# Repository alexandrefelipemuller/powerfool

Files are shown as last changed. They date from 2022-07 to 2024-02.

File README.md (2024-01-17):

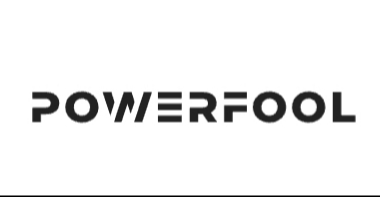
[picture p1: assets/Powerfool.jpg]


An Arduino Automobile Programmable Module

What is
---------------
It is a low cost automotive module used for many feature you want. The main idea is using Arduino Nano. It's not, at least not at first objective, a fuel injection and  spark management system. But, as it is opensource, the main idea is allow you to do anything.

Features
---------------
* Speedometer fix, by changing wheel size or other difference it can drift the signal
* Oil and fuel pressure sensor and warnings
* old Renault/General Motors Computer Board with distance per consume and autonomy (may work on other manufacturers)
* Shift light, shift stage, low battery warning, etc...
* Air temperature and oxygen sensor adjustment for tuning
* Emergency stop signal

Where to buy
---------------
You can make your own hardware using diagrams and source code on this site.

Support
---------------
Please contact autor and use Wiki here no Github

Diagram
---------------
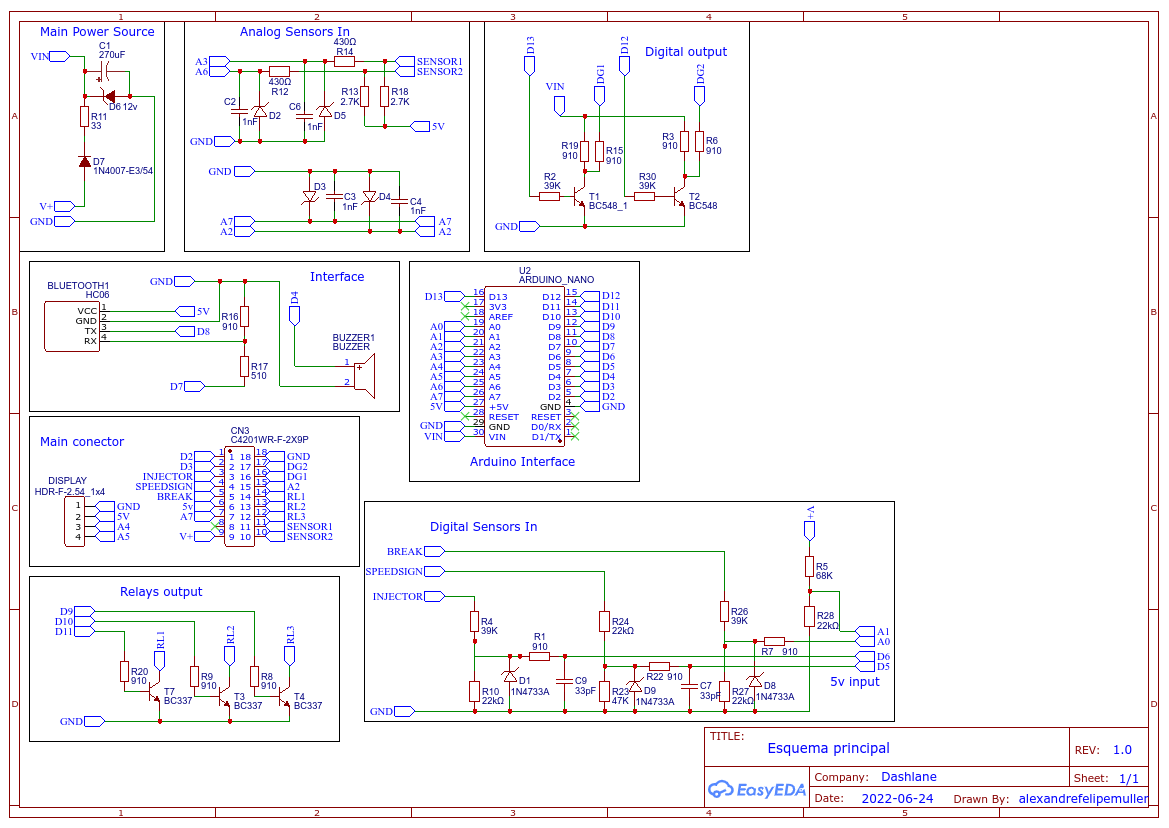
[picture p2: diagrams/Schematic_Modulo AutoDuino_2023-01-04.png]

A better explanation here: [Schematic Overview](Schematic.md)

# Understanding the Arduino Code for Vehicle Monitoring

This Arduino sketch (a term for an Arduino program) is designed for a vehicle or engine management system. It uses various sensors to monitor and control the engine's performance. Let's break down what each part does:

## 1. Sensor Inputs and Actuator Outputs:
   - The code sets up digital and analog inputs and outputs (I/O). Inputs read data from the environment (like a button press or a sensor reading), while outputs allow the Arduino to interact with other devices (like turning on a light or activating a motor).

## 2. Display and Bluetooth Communication:
   - The system is capable of displaying information on an LCD screen and communicating via Bluetooth. This might be used to show real-time data or for remote diagnostics.

## 3. Reading Sensor Values:
   - Sensors for pressure (`sensorPressure`), intake air temperature (`intakeAirTemp`), and another pressure sensor (`sensorPressure2`) are read by the Arduino. These measurements are crucial for understanding how well the engine is running.

## 4. Fuel Consumption Calculation:
   - The code computes fuel consumption based on the injector's pulsing frequency and their flow rate, which is defined as 20 lbs/h at 12V.

## 5. Speed Management and Alerts:
   - There are functions to handle speed limits, automatic door locking at certain speeds, and emergency braking indicators.

## 6. Odometer and Mileage Tracking:
   - The system keeps track of distance traveled and fuel used, functioning as an odometer and trip meter, which are saved in non-volatile memory (EEPROM) to be retained even after the power is turned off.

## 7. RPM and Pressure Management:
   - Alerts are generated if the engine's RPM exceeds a set limit or if sensor pressure drops below a certain threshold while at high RPMs.

## 8. Diagnostic Mode:
   - A diagnostic mode can display detailed reports on the LCD, which could be helpful for troubleshooting.

## 9. Timers and Pulse Outputs:
   - Timers are used to precisely manage pulse outputs for controlling various timed functions, possibly related to the engine control.

### Code Components:

- `#define`: These lines define constants or settings that can be easily changed at the top of the code.
- `#include`: This includes libraries that add functionality, like controlling an LCD screen or handling Bluetooth communication.
- Variables: Variables like `sensorPressure` are named locations in memory where sensor data is stored.
- `setup()`: A function that runs once when the Arduino is powered on. It's used to initialize I/O pins and set up communication.
- `loop()`: This function runs repeatedly, forming the main part of the program. It reads sensors, calculates values, and responds to changes.
- Functions: These are blocks of code that perform specific tasks, like `calculateDistance()` or `alertsManager()`, and can be called whenever those particular tasks need to be performed.
  
### Powerfool Project Architecture

This document outlines the proposed software architecture for the Powerfool project. The architecture is designed to enhance modularity, clarity, and ease of maintenance.

#### 1. Core Application
- **File**: `powerfool.ino`
- **Description**: The main entry point of the application. It initializes the system, manages the main loop, and coordinates high-level application flow.
- **Responsibilities**:
  - System Initialization
  - Main Loop Control
  - High-Level State Management

#### 2. Communication Module
- **Files**: `bluetooth.ino`, `bluetooth.h`
- **Description**: Handles all Bluetooth-related functionalities.
- **Responsibilities**:
  - Bluetooth Connection Management
  - Data Transmission and Reception
  - Error Handling in Communication

#### 3. Display Module
- **Files**: `display.ino`, `display.h`
- **Description**: Manages the user interface on the display.
- **Responsibilities**:
  - Rendering UI Elements
  - Displaying Status and Notifications
  - Handling Screen Refresh and Updates

#### 4. Input/Output Tools
- **Files**: `iotools.ino`, `iotools.h`
- **Description**: Manages input/output operations, including reading sensors or interfacing with other hardware components.
- **Responsibilities**:
  - Sensor Data Acquisition
  - Actuator Control
  - Input Processing

#### 5. Menu System
- **Files**: `menu.ino`, `menu.h`
- **Description**: Handles the menu interface for user interactions.
- **Responsibilities**:
  - Menu Navigation
  - User Input Handling
  - Menu-related Display Updates

#### Additional Recommendations
- **Configuration File**: `config.h` file for all global settings and constants.

### EEPROM Memory:
- The EEPROM is a type of memory that retains its contents even when the power is turned off. It's used here to store important values like total mileage and settings.
- See in menu.ino the description of the main memory

### Arduino Pins:
- Pins are the points on the Arduino board where you connect sensors and actuators. In the code, `A0`, `A1`, etc., refer to analog input pins, and numbers like `10`, `11`, `12` refer to digital I/O pins.

## In Conclusion:
This sketch is a comprehensive program for a vehicle monitoring system. It's designed to interact with the physical world through sensors and actuators, perform calculations, and save important information for future use. For a beginner, understanding this code can be a fantastic introduction to the world of embedded systems and automotive electronics.

---

*Remember, the best way to learn is by doing. So, if you're a beginner, try uploading this code to an Arduino and see what each part does. Change values, see how the system responds, and get a feel for how software can control hardware.*

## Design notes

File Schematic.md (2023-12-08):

# Principal Schematic Overview

The schematic represents a simple electronic circuit, potentially for a vehicle's monitoring or control system. Here is a breakdown of its sections:

## Main Power Source
- The main power input is denoted by `V+` and `GND` symbols.
- There's a stabilizing circuit with a `C1` capacitor for smoothing voltage fluctuations in VIN (12v).

## Analog Sensors In
- Two sensors (`SENSOR1` and `SENSOR2`) are connected through resistors to the analog inputs `A3` and `A6`.
- Each sensor circuit includes a diode for protection and a filtering capacitor.

## Digital Output
- The digital output section features two transistors (`BC548`) that control digital signals, likely to power devices or for signal processing.

## Interface
- A Bluetooth module (`HC06`) is wired for serial communication, indicated by `RX` and `TX` lines.
- There's a buzzer (`BUZZER1`) connected through a resistor and a transistor, used for audible alerts.

## Main Connector
- A connector (`CN3`) is illustrated with multiple lines for `DISPLAY`, `INJECTOR`, `SPEEDSIGN`, `BREAK`, and `SENSORS`, suggesting multiple input and output connections for various subsystems.

## Arduino Interface
- An Arduino Nano (`U2`) is shown with connections to digital and analog pins, demonstrating the integration of a microcontroller for processing and control.

## Digital Sensors In
- There are additional inputs for digital sensors, with a resistor and capacitor network for signal conditioning.

## Relays Output
- Several relays (`D9`, `D10`, `D11`) are connected, which are controlled by transistors (`BC337`). These relays likely switch higher power loads.

## 5V Output
- A separate output for 5V is indicated, which might be used for sensors

---

This schematic is indicative of a multi-faceted electronic system with capabilities for sensor integration, actuator control, power management, and communication interfaces, which could be part of an automotive or robotic application.

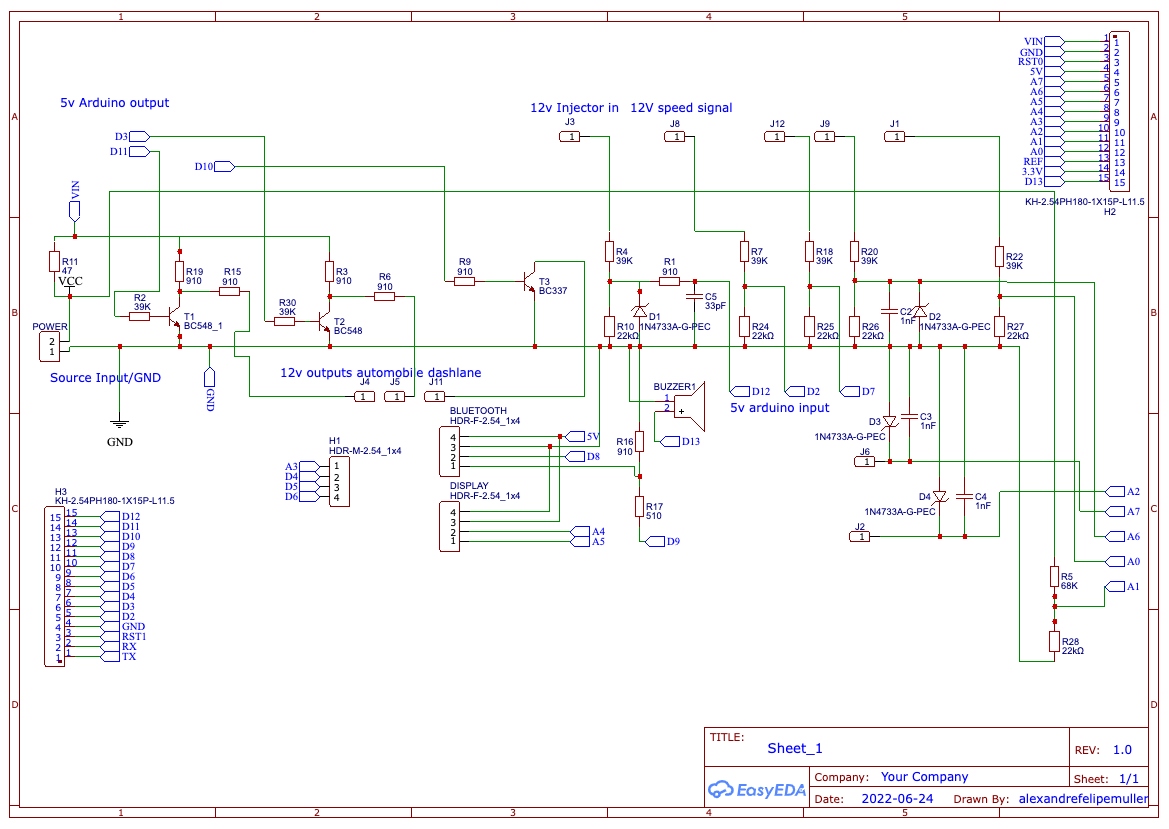
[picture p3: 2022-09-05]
diagrams/Schematic_Modulo AutoDuino_2022-09-05.png

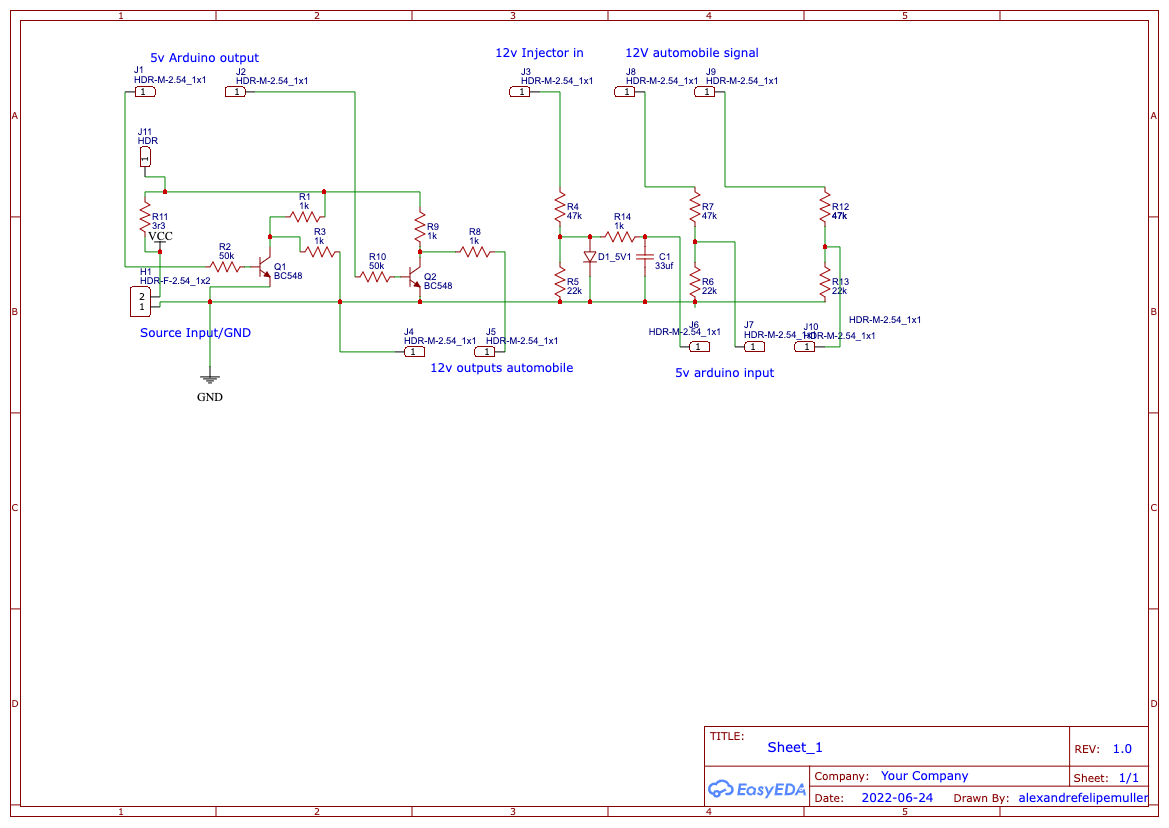
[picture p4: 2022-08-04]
diagrams/Schematic_Modulo AutoDuino_2022-07-21.png

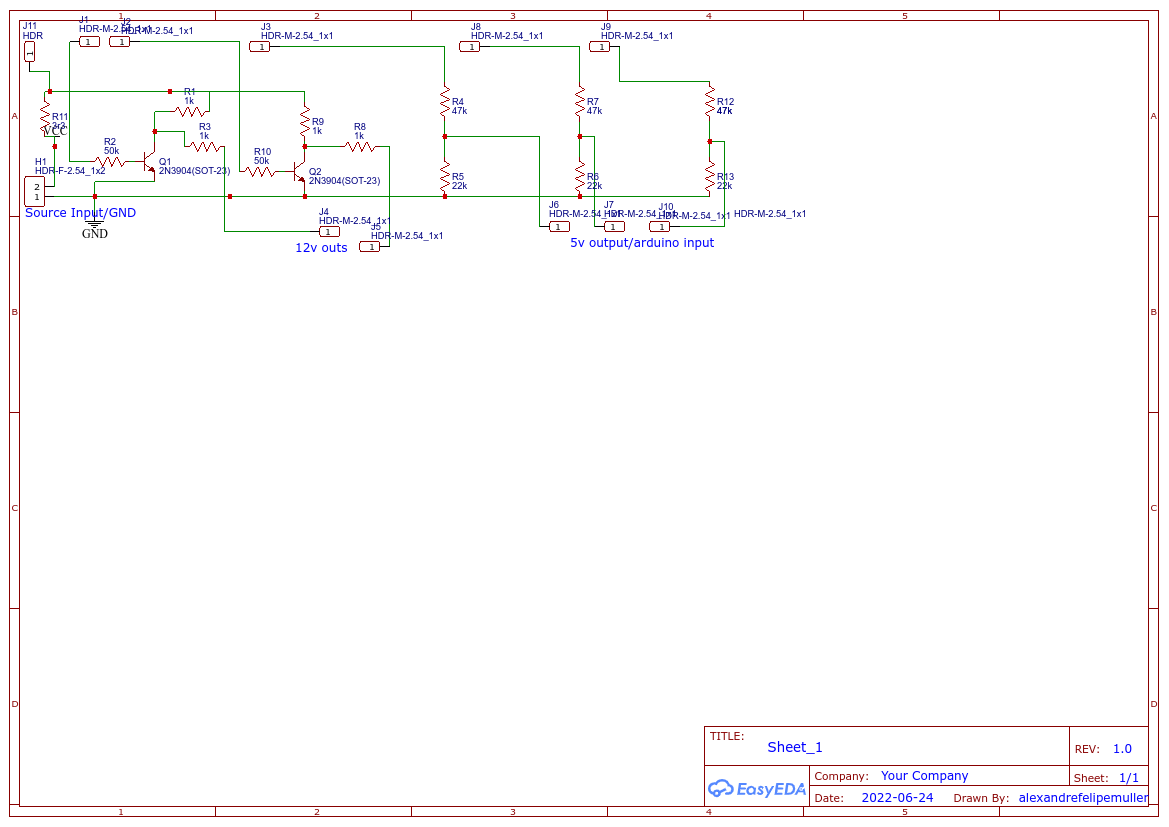
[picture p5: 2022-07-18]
diagrams/Schematic_Modulo AutoDuino_2022-07-18.png

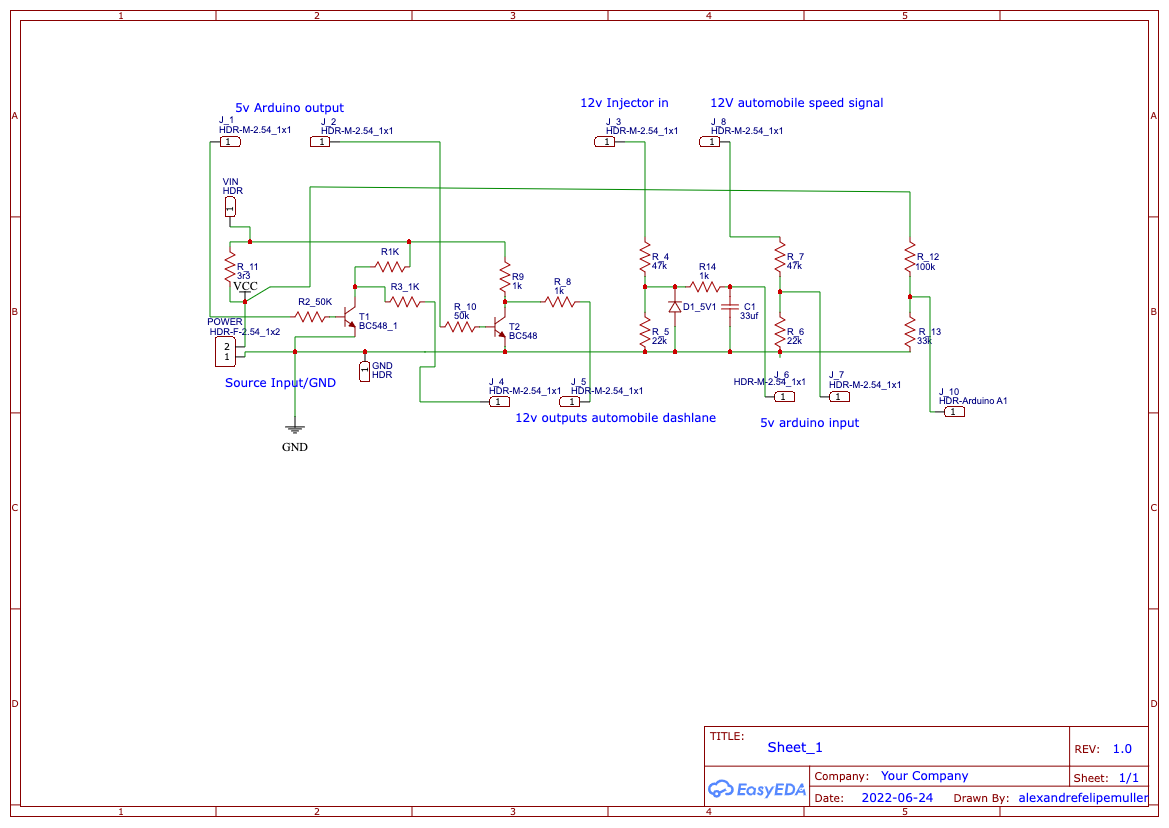
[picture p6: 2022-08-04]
diagrams/Schematic_Modulo AutoDuino_2022-08-04.png

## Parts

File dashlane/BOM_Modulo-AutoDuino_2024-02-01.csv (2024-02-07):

ID | Name | Designator | Footprint | Quantity | Manufacturer Part | Manufacturer | Supplier | Supplier Part | Price | Pins | Resistance
1 | BZT52C12_C727004 | D06 | SOD-123_L2.7-W1.7-LS3.8-RD | 1 | BZT52C12 | TWGMC(台湾迪嘉) | LCSC | C727004 | 0.013 | 2
2 | 220uF | C1 | CAP-TH_BD8.0-P3.50-D0.6-FD | 1 | KM227M035F12RR0VH2FP0 | CX(承兴) | LCSC | C2063 | 0.027 | 2
3 | Bluetooth | U1 | HDR-TH_4P-P2.54-H-F-W10.2 | 1 | KH-2.54FH90-1X4P-H8.5 | kinghelm(金航标) | LCSC | C2932680 | 0.076 | 4
4 | BC337 | T1 | BC548C | 1 | BC337 | Jiangsu Changjing Electronics | LCSC | C328602 | 0.016 | 3
5 | BC337 | T2 | BC548C | 1 | BC337 | Jiangsu Changjing Electronics Technology Co., Ltd. | LCSC | C328602 | 0.016 | 3
6 | 33pF | C7,C9 | C0603 | 2 | GRM1882C1H330JA01D | muRata(村田) | LCSC | C85970 | 0.006 | 2
7 | 430Ω | R12,R14 | RES-TH_BD1.8-L3.2-P7.20-D0.4 | 2 | MF1/8W-430Ω±1%T52 | Huaxing Mechanical-Elec. | LCSC | C713906 | 0.005 | 2 | 430Ω
8 | 2.7K | R13,R18 | RES-TH_BD2.4-L6.3-P10.30-D0.6 | 2 | MFR-25FTE52-2K7 | YAGEO | LCSC | C172999 | 0.011 | 2 | 2.7kΩ
9 | C4201WR-F-2X9P | CN3 | CONN-TH_C4201WR-F-2X9P | 1 | C4201WR-F-2x9P | CJT(Changjiang Connectors) | LCSC | C428857 | 0.552 | 18
10 | HDR-F-2.54_1x4 | DISPLAY | HDR-F-2.54_1X4 | 1 |  |  | LCSC | C225501 | 0.071 | 4
11 | 910 | R7,R22,R20,R8,R1,R3,R6,R9,R15,R16,R19 | RES-TH_BD1.8-L3.2-P7.20-D0.4 | 11 | MF1/8W ±1% 910Ω OTB5E | FlyWin | LCSC | C337120 | 0.006 | 2 | 910Ω
12 | 33 | R11 | RES-TH_BD3.3-L9.0-P13.00-D0.6 | 1 | MFR1WSJT-52-33R | YAGEO | LCSC | C176430 | 0.025 | 2 | 33Ω
13 | 1N4733A | D9,D8,D5,D1,D2 | DO-41G_BD2.4-L4.0-P8.00-D0.7-RD | 5 | 1N4733A-G-PEC | PANJIT International | LCSC | C112411 | 0.06 | 2
14 | 47K | R23 | RES-TH_BD1.7-L3.5-P7.50-D0.5 | 1 | RN 1/8W 47K F T/B A1 | TyoHM | LCSC | C433476 | 0.008 | 2 | 47kΩ
15 | ARDUINO_NANO | U2 | COMM-TH_ARDUINO_NANO | 1 | ARDUINO_NANO | null | LCSC | C9900017879 |  | 30
16 | 39K | R26,R2,R4,R30 | RES-TH_BD2.3-L3.7-P7.70-D0.9 | 4 | - | FlyWin | LCSC | C337041 | 0.003 | 2 | 39kΩ
17 | 22kΩ | R27,R10,R24,R28 | RES-TH_BD1.8-L3.2-P7.20-D0.4 | 4 | MF1/8W-22KΩ±1%T52 | Huaxing Mechanical-Elec. | LCSC | C713923 | 0.006 | 2 | 22kΩ
18 | BC337 | T7,T4,T3 | BC548C | 3 | BC337 | Foshan Blue Rocket Elec | LCSC | C328602 | 0.016 | 3
19 | 1nF | C6,C4,C3,C2 | C0603 | 4 | CL10B102KB8NNNC | SAMSUNG | LCSC | C1588 | 0.003 | 2
20 | 1N4007-E3/54 | D7 | DO-41_BD2.4-L4.7-P8.70-D0.9-FD | 1 | 1N4007-E3/54 | VISHAY | LCSC | C3011149 | 0.011 | 2
21 | BUZZER | BUZZER1 | BUZ-TH_BD12.0-P7.60-D0.6-FD | 1 | TMB12A05 | YUEXIN | LCSC | C781860 | 0.214 | 2
22 | 1N4733A-G-PEC | D3,D4 | DO-41G_BD2.4-L4.0-P8.00-D0.7-RD | 2 | 1N4733A-G-PEC | PANJIT International | LCSC | C112411 | 0.06 | 2
23 | 68K | R5 | RES-TH_BD1.8-L3.2-P7.20-D0.4 | 1 | - | Chian Chia Elec | LCSC | C119221 | 0.008 | 2 | 68kΩ
24 | 510 | R17 | RES-TH_BD1.9-L3.4-P7.40-D0.5 | 1 | MFR-12JT-52-510R | YAGEO | LCSC | C176393 | 0.015 | 2 | 510Ω

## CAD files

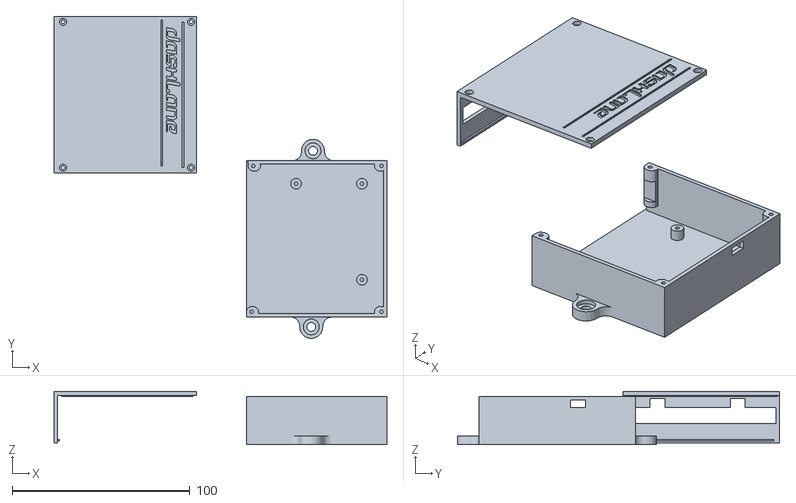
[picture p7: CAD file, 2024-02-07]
dashlane/Dashlane case.stl
187.0 x 181.0 x 30.0

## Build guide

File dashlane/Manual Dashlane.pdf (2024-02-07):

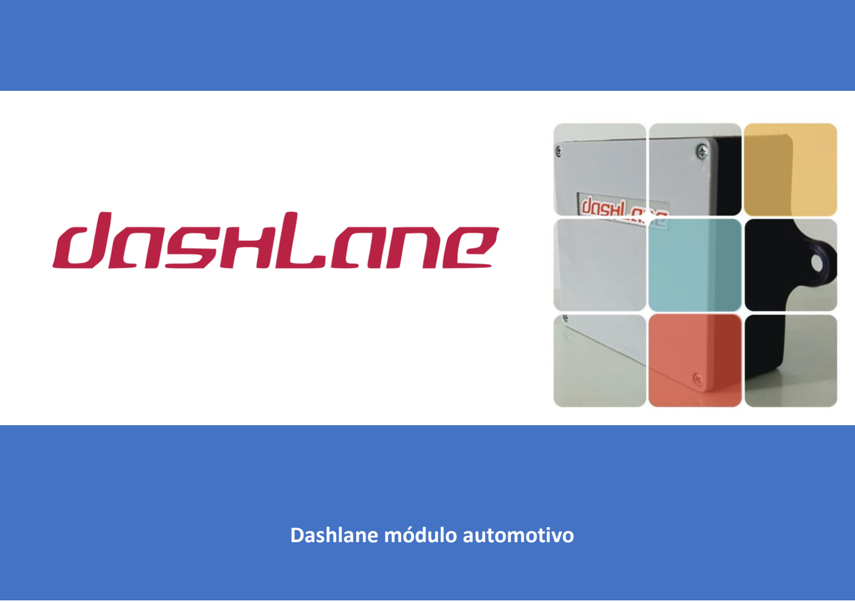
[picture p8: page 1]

0

## Dashlane módulo automotivo

## Introdução

1

1

## Introdução

2

2

## Índice

Seção 2) | Computador de bordo original ........4
Seção 3) | Aviso de frenagem de emergência...4
Seção 4) | Abertura e fechamento de portas....4
Seção 1) | Diagrama do conector principal.......6

Menu 3 – Velocidade média, consumo médio .........11

## Introdução

3

3

Capítulo 5 Firmware e informações gerais.......18

Seção 1) | CopyLeft e ausência de garantia ....18
Seção 1) | Vista interna e descrição

## Introdução

4

4

## Capítulo 1 Introdução

Parabéns! Ao adquirir esse produto você agora faz parte de uma comunidade. O módulo Dashlane é um microcontrolador programável que pode ser usado e modificado.

### Seção 1) Apresentação

Ver anexo, o Módulo possui duas portas de comunicação:
- Chicote principal, conector minifit 18 vias
- Porta USB

## Capítulo 2 Funções

### Seção 1) Divimult

Permite ajustes sinal de velocidade para mais ou para menos, para ajustes de diferença de sensor, roda ou painel. Correção do hodômetro.

### Seção 2) Computador de bordo original

Cálculo do combustível consumido através de leitura de um injetor, e saída de consumo para painéis que utilizam esse sinal.

### Seção 3) Aviso de frenagem de emergência

Sinalização de frenagem de emergência: automaticamente o pisca-alerta entra em funcionamento quando o carro é freado bruscamente, servindo de alerta aos outros motoristas. Padrão acima de 80 km/h desaceleração superior a 7 m/s²

### Seção 4) Abertura e fechamento de portas

Travamento das portas quanto atinge determinada velocidade.

## Funções

5

5

### Seção 5) Avisos sonoros

Aviso sonoro de limitador de velocidade e rotação excessiva do motor.

### Seção 6) Proteções do motor

Leitura de sinal de pressão (seja óleo ou combustível), ou temperatura para proteção do motor.

### Seção 7) Display LCD

Ver as principais informações através de um display LCD avulso.

### Seção 8) Bluetooth

Ver as principais informações através do aplicativo RealDash para Android.

### Seção 9) Cronômetro de volta

Marcar tempo de volta através de um botão instalado a parte.

## Instalação

6

6

## Capítulo 3 Instalação

### Seção 1) Diagrama do conector principal

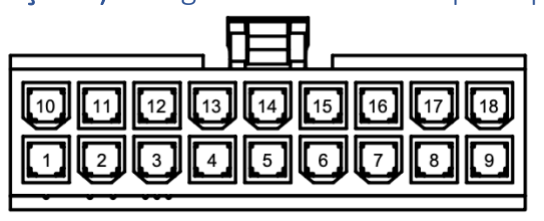
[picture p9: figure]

Atenção: Vista de frente do módulo

PINO | FUNÇÃO
1 | + Pós Chave 12v
2 | Sem uso
3 | Entrada 1 Analógica 5v (sensor 3 fios)
4 | + Saída 5v para Sensores
5 | Entrada Digital 3, Sensor 12v
6 | Entrada Digital 2, Sensor 12v
7 | Entrada Digital 1, Sensor 12v
8 | - Botão 1
9 | - Botão 2
10 | - Negativo
11 | Saída 1 digital 12v (painel)
12 | Saída 2 digital 12v (painel)
13 | Entrada 2 Analógica 5v (sensor 3 fios)
14 | Saída Relé 1
15 | Saída Relé 2
16 | Saída Relé 3
17 | Sensor 1 (resistivo)
18 | Sensor 2 (resistivo)
Atenção: As cores dos fios não possuem padrão, podem variar de um chicote a outro e portanto devem ser desconsideradas.

### Seção 2) Informações importantes

Antes de começar qualquer instalação elétrica desconecte os polos da bateria. É aconselhável ligar negativo do módulo diretamente ao negativo da bateria. É indispensável uso de ferramentas como multímetro ou caneta testadora.

## Instalação

7

7

A ligação inadequada apresentará possível dano irreversível. Por tanto certifique-se que está ligando corretamente o sinal.
Planeja-se e determine onde a central será instalada e quais dispositivos serão conectados (sensores, painéis de controle, etc.). Também que o componente de campainha interno será audível.

Fios não utilizados devem obrigatoriamente ser isolados.

### Seção 3) Sugestão de ligação básica

- Negativo – Direto da bateria
- Positivo – Pós chave
- Entrada Digital 1 – Negativo do Bico injetor (veja detalhes a seguir)
- Entrada Digital 2 – Sensor de velocidade, roda ou caixa de marcha. Entrada de velocidade (necessário para Computador de Bordo)
- Entrada Digital 3 – Luzes de freio (somente se for usar ESS)
- Saída Digital 1 - Saída de
consumo (ver a seguir)
- Saída Digital 2 - velocidade (painel), Somente se for utilizar divimulti

Como encontrar sinal do negativo do bico injetor: De um injetor qualquer, testar com injetor desconectado entre os dois fios, qual fio possui 12v no pós chave e ligar no outro fio.

Sinal de consumo no painel (somente para computador de bordo original):
Renault Sandero/Logan painel digital - pino 19 tomada cinza
Renault Clio/Scenic mostrador do tanque com ponteiro - pino 7 tomada vermelha
Uno mile fire - MR/ AM pino B08 Corsa/Classic/Vectra B- pino 27 MID (painel central)

Se o pino estiver faltando no plug usar um conector femea kk tipo molex.

## Instalação

8

8

Sinal de velocidade (para ser usado sinal para entrada ou saída):
Renault Sandero/Logan painel digital - pino 22 tomada preta do painel
Renault Clio/Scenic mostrador do tanque com ponteiro - pino 23 tomada cinza do painel
Ou sensor da caixa.
Saída do módulo para o painel
Tipicamente 27 Hz = 20km/h, 135Hz = 100 km/h

Botão troca de menu do computador de bordo original.
Caso queira utilizar computador de bordo original do painel é necessário instalar botão com sinal negativo (que vai pro painel diretamente):
Renault Sandero/Logan painel digital - pino 23 tomada preta do painel
Renault Clio/Scenic mostrador do tanque com ponteiro - pino 6 tomada vermelha do painel Corsa/Classic - pino 24 MID

### Seção 4) Fechamento de portas

Ao atingir determinada velocidade configurada pelo terminal USB a saída “Rele 2” é acionada por 400 milissegundos. Nessa saída deve ser ligado o botão de travamento de portas onde será acionado o travamento.
No fio correspondente a essa porta haverá um sinal negativo como na figura 1 na seção seguinte. Não ultrapassar corrente de 1A nessa porta.

### Seção 5) Frenagem de emergência ESS

Ao atingir desaceleração superior a 7m/s²

a saída
“Rele 3” é acionada por 500 milissegundos. Nessa saída deve ser ligado o botão alerta onde será acionado o alerta. Esse recurso só funciona com sinal de freio na porta entrada digital 3.
No fio correspondente a essa porta haverá um sinal negativo como na figura 1 na seção

## Instalação

9

9

seguinte. Não ultrapassar corrente de 1A nessa porta.

Seção 6) Divimult
Caso vá utilizar a função Divimult será necessário ligar Entrada Digital 2 e Saída Digital 2 do Dashlane. Podendo ser sensores indutivos ou hall. A saída do dashlane necessariamente é uma onda quadrada.

### Seção 7) Proteções do motor

É possível implementar até 2 sensores de pressão do tipo PS10 que monitoram condições de baixa pressão de óleo ou combustível.

Para esta função a instalação precisa ter:
- Rele 1 – Por exemplo rele normalmente fechado ligado em série na bobina
- Entrada Digital 1 sinal do RPM ( por ex. bico injetor)
- Saída 5v estabilizada
- Entrada sinal analógico (pino 3 ou 13)

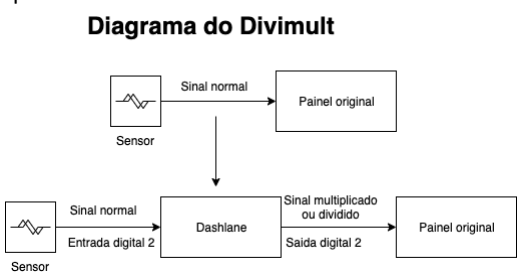
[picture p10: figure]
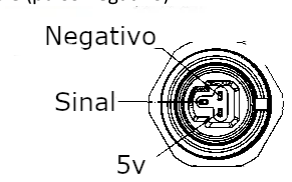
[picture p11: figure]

Saída relé (pulso negativo)

## Instalação

10

10

Relé de saída
Acionado no momento do alerta
Recomendado relé de no máximo 18 ohms, corrente máxima da saída de 1 ampere.

Devido a construção do relé com bobina interna o desligamento do relé pode gerar picos de alta tensão reversa particularmente danosa a circuitos eletrônicos. É fortemente recomendado a instalação de um diodo 1N4001 em paralelo com relé.

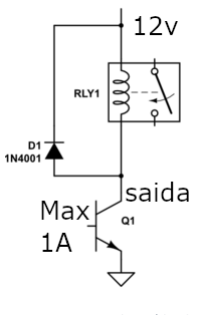
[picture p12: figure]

Figura 1 Exemplo saída de relé

Sugestões extras de ligação
- Sensor 1 – Temperatura da água radiador
- Sensor 2 – Temperatura do ar da admissão
- Rele 2 – Botão travamento das portas
- Rele 3 – Acionamento do pisca alerta

## Instalação

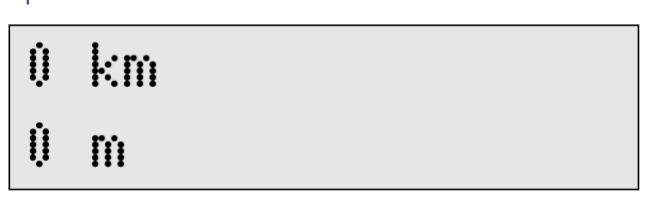
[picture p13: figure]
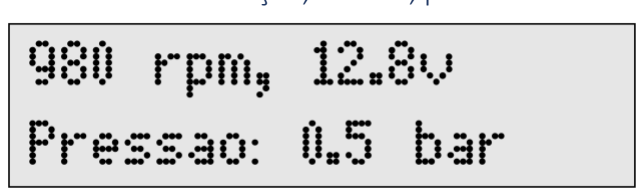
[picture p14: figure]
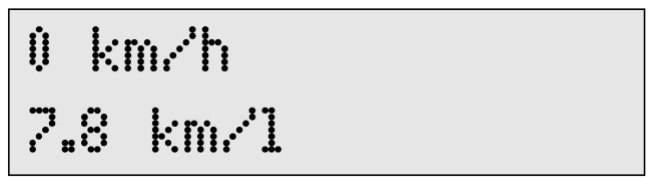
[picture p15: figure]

11

11

### Seção 8) Display

É possível instalar um display LCD 16x2 (de todas as cores) vendido separadamente.
A instalação usa 4 fios separados da tomada principal. São eles:
- Negativo
- Positivo 5v
- Sinal de Clock (SCL)
- Sinal de dados (SDA)

Se o seu módulo não possui 4 fios disponível basta conectar 4 jumpers dentro da placa principal. Mais informações veja o capítulo: Informações Técnicas

Através do Botão 1 (Menu) é possível alternar o menu do display.
Através do Botão 2 (Set) é possível configurar o menu selecionado.

Menu 1 - Hodômetro total e parcial

Menu 2 - Rotação, bateria, pressão sensor

Menu 3 – Velocidade média, consumo médio

## Instalação

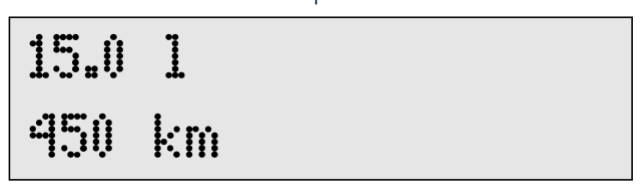
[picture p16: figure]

12

12

Menu 4 – Temperatura Sensor 1 e 2

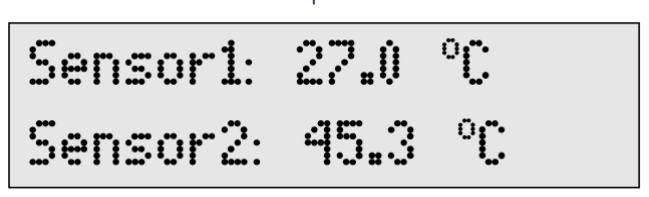
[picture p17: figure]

Menu 5 – Lap Timer

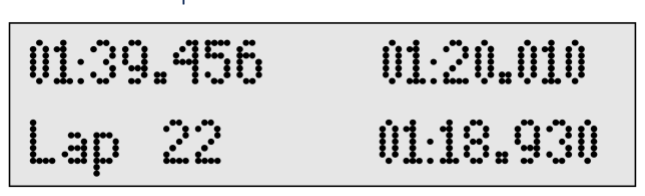
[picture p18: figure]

Tempo da volta atual e tempo da última volta. Número da volta atual e tempo de melhor volta

Menu 6 – Litros no tanque e autonomia

Litros no tanque desde que zerado hodômetro e autonomia esperada. Para atualizar a quantidade do tanque o usuário deve utilizar o botão set que soma + 5 litros.

### Seção 9) Bluetooth

É possível visualizar os dados do módulo através do aplicativo RealDash para Android

## Ajustes

## Capítulo 4 Ajustes

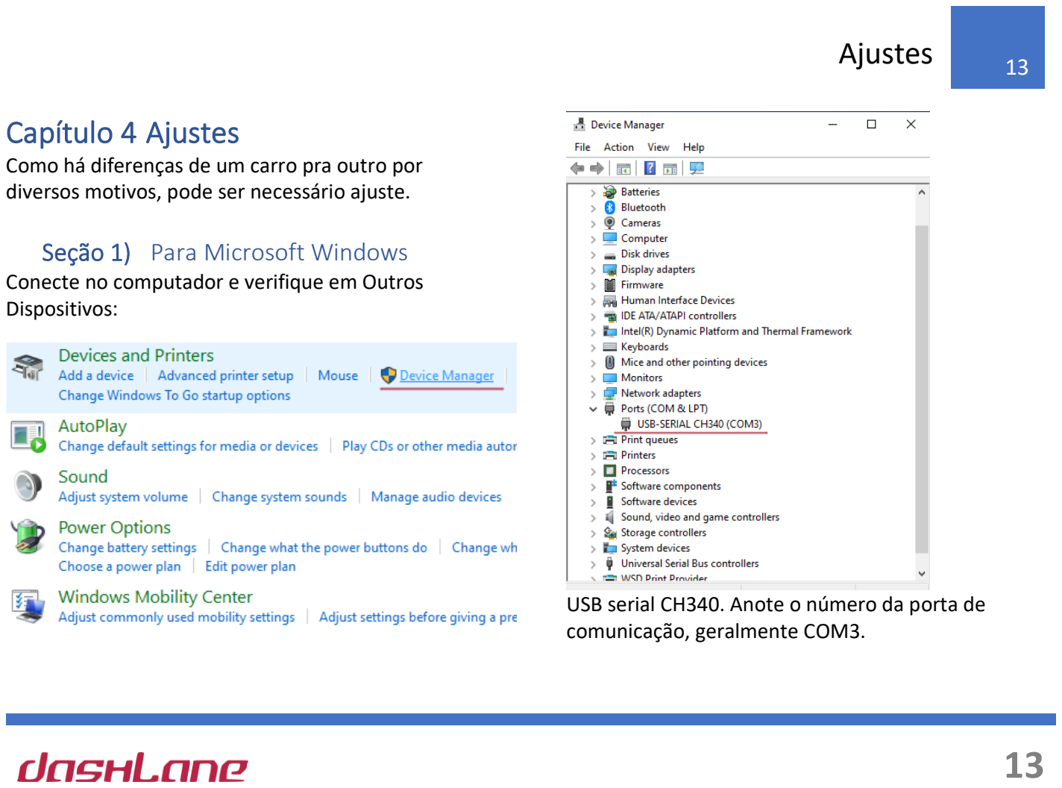
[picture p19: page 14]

13

13

Como há diferenças de um carro pra outro por diversos motivos, pode ser necessário ajuste.

### Seção 1) Para Microsoft Windows

Conecte no computador e verifique em Outros Dispositivos:

USB serial CH340. Anote o número da porta de comunicação, geralmente COM3.

## Ajustes

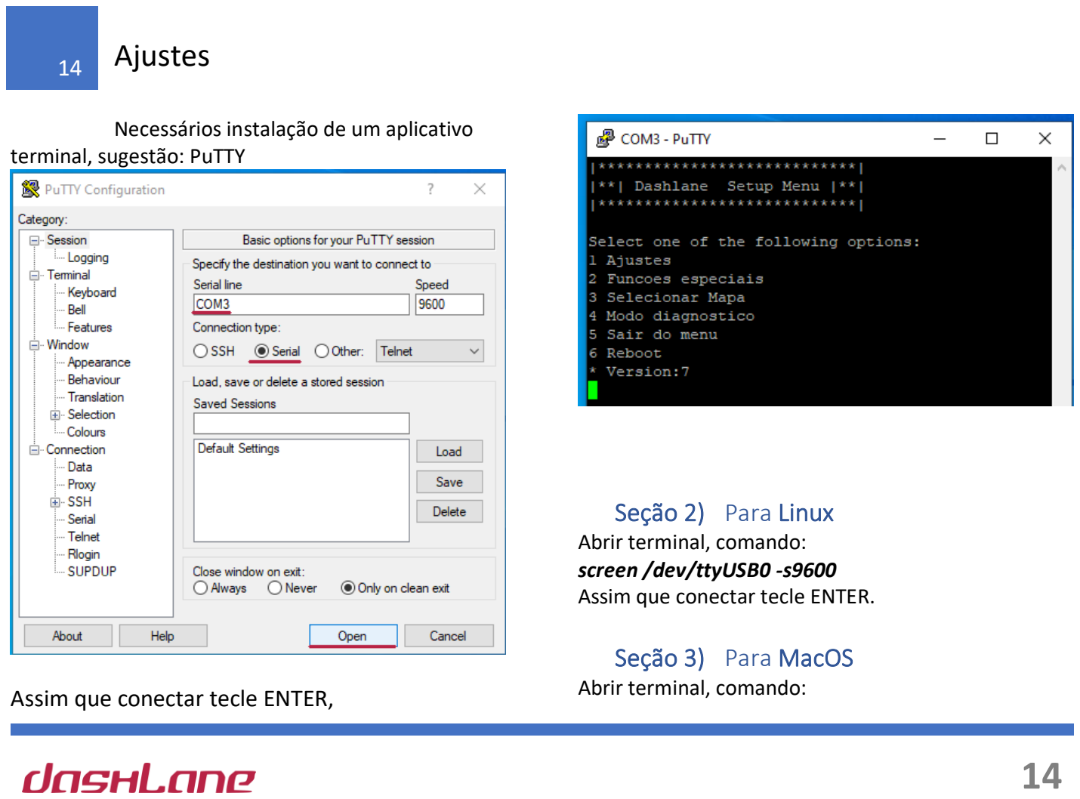
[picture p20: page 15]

14

14

Necessários instalação de um aplicativo terminal, sugestão: PuTTY

Assim que conectar tecle ENTER,

### Seção 2) Para Linux

Abrir terminal, comando:
screen /dev/ttyUSB0 -s9600 Assim que conectar tecle ENTER.

### Seção 3) Para MacOS

Abrir terminal, comando:

## Ajustes

15

15

screen /dev/*usbserial*
Assim que conectar tecle ENTER.

### Seção 4) Informações gerais

Após conectado, ligue modo diagnóstico (4) com motor funcionando para ver os valores lidos.

Todos os sinais podem ser ajustados pela porta USB em até +400% e -99%

Entrada do sensor de velocidade Aqui é possível ajustar o que é chamado de “constante K” vulgarmente falando quantos pulsos por km rodado. Esse valor usado pelo hodômetro e computador de bordo interno. Alguns valores de referencia:
- VW antigo 1800
- Renault 4860
- VW Fox 5000
- Chevrolet 15200

Ajuste do velocímetro
Permite ajustar sinal de velocidade e hodômetro em caso de troca de diâmetro das rodas, troca de sensor, troca de painel e etc...

Melhor forma de ajustar é pela distância percorrida do hodômetro, se for ajustado pela velocidade do GPS o hodômetro marcará a menos.

Tipo de injeção
Usado na referencia de rotação
Sequencial: um pulso por rotação do motor Semi-Sequencial: dois pulsos por rotação do motor

Primeiro ajuste do computador de bordo
Sinal de consumo instantâneo – Permite funcionamento de computador de bordo em painéis compatíveis com sinal de consumo instantâneo.

## Ajustes

16

16

Valor normal de consumo na marcha lenta mais ou menos 0.5ml/s
- Encha tanque, zere hodômetro. Depois de consumido, divida valor do hodômetro pelo valor consumido na bomba.

Por exemplo 500 km / 46 litros = 10,8 km/l Se medido no painel foi por exemplo 4 km/l, faça conta:
Medido no painel / Medido na bomba, por exemplo 4 / 10.8 = 0.37
- Subtraia 1 desse valor 0,37 -1 = -0,63
- O ajuste é -63% (mesmo procedimento pra valores acima do medido)
- Por exemplo se painel tivesse dado 15km/l, então 15/10.8 = 1,38. Portando 1,38 -1 = 0,38. Ajuste de +38%.

O ajuste pode ser feito por outro parâmetro: combustível consumido. Apenas medindo na bomba. Esse procedimento igualmente certo.

Ajustes Funções especiais

- Shift Beep (rpm do beep para troca de marcha, 0 desabilitado)
- RPM mínimo de acionamento do alerta (0 desabilitado)
- Pressão mínima de acionamento do alerta sensor 1 (1.000 = 1 bar de pressão)
- Pressão mínima de acionamento do alerta sensor 2 (1.000 = 1 bar de pressão)
- Aviso velocidade excedida em km/h: Velocidade em km/h que alerta com beep
- Tipo do beep de velocidade: continuo (fica alertado até velocidade baixar) ou curto (apenas dois beep curtos)

## Ajustes

17

17

- Travamento automático das portas: quantos km/h deve travar as portas na saída RL2 (0 é desabilitado).

## Firmware e informações gerais

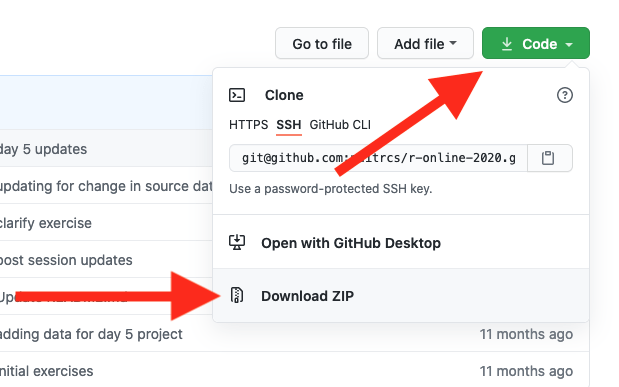
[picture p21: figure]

18

18

## Capítulo 5 Firmware e informações gerais

### Seção 1) CopyLeft e ausência de garantia

É dada liberdade de modificar, distribuir suas modificações, o código do programa que roda no módulo está disponível para estudo e modificação. Você pode alterá-lo e estuda-lo, porém suas modificações podem trazer efeitos adversos, por esse motivo somente pode ser exigido garantia com programa que esteve gravado originalmente no módulo.

### Seção 2) Baixando código fonte

Caso você deseja modificar o seu módulo para programa-lo a fazer qualquer coisa, gravar um novo firmware é o primeiro passo.

Abra o link do projetoi e clique em Clone e Download as Zip

### Seção 3) Gravando firmware novo

Faça download do Arduino IDE ii, e clique em Abrir, depois de descompactado o zip abra “powerfool.ino”.
Conecte o módulo a porta USB, feche todo e qualquer terminal que eventualmente esteja aberto.

## Firmware e informações gerais

19

19

Selecione Tools -> Selecione dispositivo Arduino Nano, no menu logo abaixo selecione tipo de processador ATmega328p (old bootloader).
Clique na seta pra direita da barra de ferramentas e espere até que apareça: “Carregado.” (deve-se ouvir o bip confirmando que o dispositivo foi reiniciado)
Esse código é feito de forma coletiva, a sua participação pode ajudar futuros usuários a terem uma melhor experiência.

## Suporte

20

20

## Capítulo 6 Suporte

Pelas redes sociais @dashlanemodulos no Instagram ou no Facebook

## Informações Técnicas

21

21

## Capítulo 7 Informações Técnicas

### Seção 1) Vista interna e descrição componentes:

BLUETOOTH | Modulo HC06
C1 | Capacitor 270uF
C2,3,4,6 Capacitor 1nF
C7,9 Capacitor 33pF
D1-5,7-9 Diodo Zener 5v.1 1N4733A
D6 | Diodo Zener 12v
R2,4,30,26 | Resistor 39K
R5 | Resistor 68K
R1,3,5,6,7,8,9,15,16,19,20,22Resistor 910R R11 Resistor 33R
R12,14 Resistor 430R
R17 Resistor 510R
R13,18 Resistor 2.7K
R23 | Resistor 47K
R10,24,27,28 | Resistor 22kΩ
T1,T2 | Transistor BC548
T3,T4,T7 Transistor BC337
U2 Arduino Nano

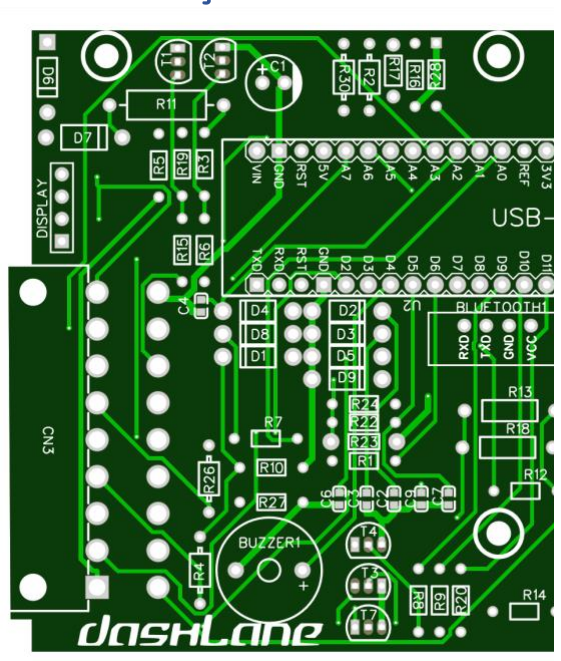
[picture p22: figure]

## Informações Técnicas

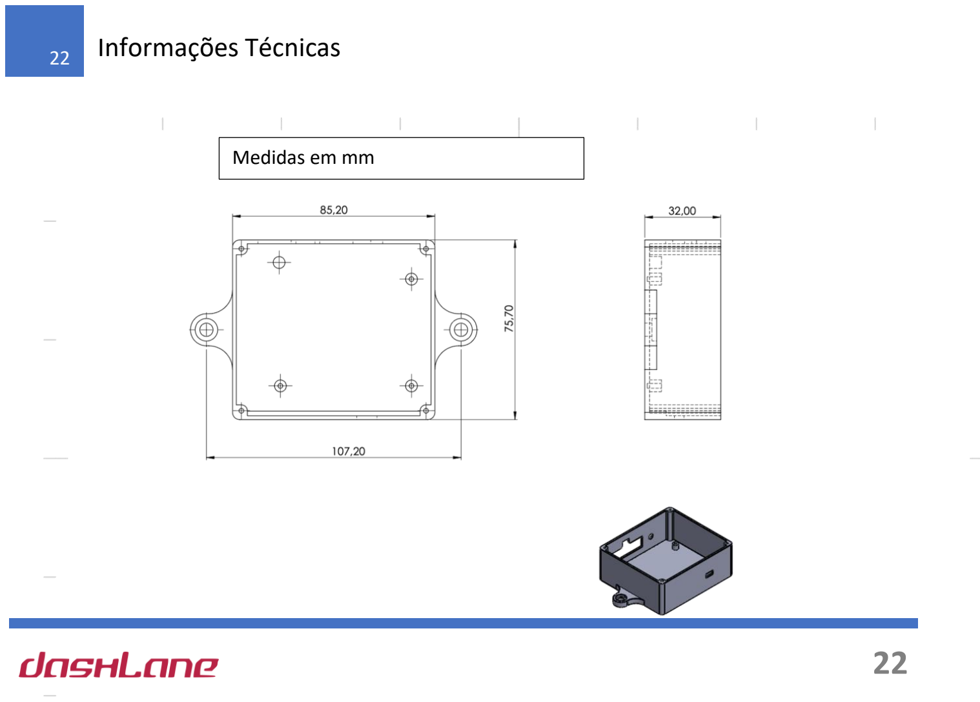
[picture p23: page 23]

22

22

Medidas em mm

## Informações Técnicas

23

23

ihttps://github.com/alexandrefelipemuller/po werfool

ii https://www.arduino.cc/en/software

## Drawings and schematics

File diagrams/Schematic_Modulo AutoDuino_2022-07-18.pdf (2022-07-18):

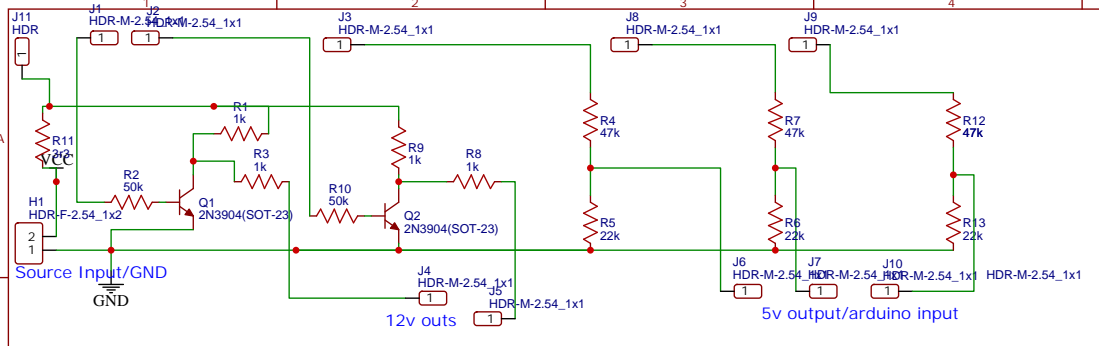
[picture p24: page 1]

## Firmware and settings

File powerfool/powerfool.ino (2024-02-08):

#define BUILD_DISPLAY
#define BUILD_BLUETOOTH
//#define is_ESP32

#include <EEPROM.h>
#include "menu.h" 
#include "iotools.h"
#include "memutils.h"
//DISPLAY
#include "display.h"
#include <Wire.h>
#include <LiquidCrystal_I2C.h>
LiquidCrystal_I2C lcd(0x27,16,2);  // set the LCD address to 0x27 for a 16 chars and 2 line display
//BLUETOOTH
#include "bluetooth.h"
#include <SoftwareSerial.h>
SoftwareSerial BTSerial (8,9);

#define timer_freq 3000

#define setButton 2
#define menuButton 3
#define beep 4
#define DI2 5
#define DI1 6
#define DI3 A0
#define RL3 7
#define RL2 10
#define RL1 11
#define DO1 12
#define DO2 13
#define voltageIn A1 // internal
#define sensorPressure A2
#define intakeAirTemp A3
#define sensorTemp A6
#define sensorPressure2 A7

#define injetor 20.0 // vazao do injetor a 12v, em lbs/h

// set up pulse pins
#define n_saidas_pulso 3
float out_freq[n_saidas_pulso] = {1,1,1};

//Define pinos para pulsar, devem ser iniciador em setup
int pulse_pin[n_saidas_pulso] = {-1,-1,-1}; 

//Define correção para cada saide de pulso
int correction_drift[n_saidas_pulso] = {0,0,0}; 

// Contadores para cada pino, incrementados pela ISR
volatile unsigned long pulseCounters[n_saidas_pulso] = {0, 0, 0};

// Armazena o número total de interrupções necessárias para cada estado (HIGH e LOW)
unsigned long totalInterruptsForCycle[n_saidas_pulso];



bool diagnostic_mode = false;

unsigned long last_millis, totalMileage, tripA;
unsigned int rpmLimit, rpmAlert, minPressure, speedSensor, settings, rpm;

unsigned char speedLimit, lastSpeed;
bool doorLocked = false, speedBeep = false, rpmBeep = false;

float odometer = 0;
float fuel = 0;
unsigned int tank;
unsigned char doorLockspd;

unsigned char RL_P, RL_DL, RL_HZ, speed_in_pin, injector_pin, breakLight;
unsigned char consume_pin = DO1;
unsigned char speed_out_pin = DO2;

void setup()
{
  Serial.begin(9600);
  pinMode(DI1,INPUT);
  pinMode(DI2,INPUT_PULLUP);
  pinMode(DI3,INPUT);
  pinMode(voltageIn, INPUT);
  pinMode(sensorPressure,INPUT);
  pinMode(sensorPressure2, INPUT);
  pinMode(intakeAirTemp,INPUT);
  pinMode(sensorTemp,INPUT);
  pinMode(beep, OUTPUT);
  pinMode(DO2,OUTPUT);
  pinMode(DO1,OUTPUT);
  pinMode(RL1,OUTPUT);
  pinMode(RL2,OUTPUT);
  pinMode(RL3,OUTPUT);
  pinMode(setButton,INPUT_PULLUP);
  pinMode(menuButton,INPUT_PULLUP);
  
  #ifdef BUILD_DISPLAY
  attachInterrupt(digitalPinToInterrupt(setButton), setMenu, RISING);  
  attachInterrupt(digitalPinToInterrupt(menuButton), changeMenu, RISING);
  #endif
  pulse_pin[0]=consume_pin;
  pulse_pin[1]=speed_out_pin;
  pulse_pin[2]=beep;
  
  loadMemoryValues();
  setupTimer1(); 

  #ifdef BUILD_DISPLAY
    lcd.init();
    lcd.createChar(0, degreeSymbol);
    lcd.backlight(); 
  #endif
  #ifdef BUILD_BLUETOOTH
    BTSerial.begin(9600);
  #endif
   pulsePinOnce(beep,500);
}

#ifdef is_ESP32
  hw_timer_t *esp_timer = NULL;
  void setupTimer1(){
      esp_timer = timerBegin(0, 80, true);
      timerAttachInterrupt(esp_timer, &onTimer, true);
      timerAlarmWrite(esp_timer, (1000000/timer_freq), true);
      timerAlarmEnable(esp_timer);
  }
#else
  void setupTimer1(){
  noInterrupts(); // Desativa interrupções durante a configuração
  // Configuração do Timer1
  TCCR1A = 0;
  TCCR1B = 0;
  OCR1A = (F_CPU / 5000 / 1024) - 1; // Define a frequência das interrupções do Timer1
  TCCR1B |= (1 << WGM12) | (1 << CS12) | (1 << CS10); // Modo CTC, prescaler de 1024
  TIMSK1 |= (1 << OCIE1A); // Habilita interrupção do Timer1 (TIMER1_COMPA_vect)
  interrupts(); // Reativa interrupções
  }
#endif


void loop()
{
  if (Serial.available() > 0)
    Menu();

  #ifdef BUILD_DISPLAY
  if (digitalRead(setButton) != LOW)
    releaseSetButton();
  if (digitalRead(menuButton) != LOW)
    releaseMenuButton();
  #endif
  
  float volts = analogRead(voltageIn)*0.0197f;
  
  inputFreq injectorInput, speedInput;
  readFrequency(injector_pin, 2, &injectorInput);
  float duty;
  if ((float)(injectorInput.period) == 0.0f)
    duty=0.0;
  else
    duty = (float)injectorInput.offtime/(float)(injectorInput.period); 
   
  float vazao = injetor * (0.126); // result in ml/s 
  float consumption = injectorInput.freq*vazao*duty;

  readFrequency(speed_in_pin, 4, &speedInput);
  
  if (getBit(2)) //if is test
  {
    pinMode(injector_pin,INPUT_PULLUP);
    pinMode(speed_in_pin,INPUT_PULLUP);
    setOutFrequency(120.0f,0);
    setOutFrequency(120.0f,1); 
  }
  else{
    if (injectorInput.period == 0.0)
      setOutFrequency(0.0,0);  
    else
      setOutFrequency(consumption/0.083f,0); 
    
    if (speedInput.period == 0.0)
      setOutFrequency(0.0,1);  
    else
      setOutFrequency(speedInput.freq,1);
  
     //Calculate distance and consumed fuel
     calculateDistante(millis() - last_millis);    
  }
  
  //Speed
  unsigned char currentSpeed = (unsigned char) (out_freq[1]/((float) (speedSensor/3600.0f)));    
  speedManager(currentSpeed);
  
  last_millis = millis();
  
  // Alerts
  if (injectorInput.freq > 0)
    rpm = injectorInput.freq*60*((getBit(1)+1)*2);
  
  int sensorPressureVal = alertsManager(rpm);

  if (diagnostic_mode){
    clearScreen();
    diagnosticReport(injectorInput, speedInput, consumption, volts, sensorPressureVal);
    delay(200);
  }
  #ifdef BUILD_DISPLAY
    refreshMenu(injectorInput, speedInput, consumption, volts, sensorPressureVal);
  #endif
  #ifdef BUILD_BLUETOOTH
    sendBluetooth(rpm, currentSpeed, volts, sensorPressureVal);
  #endif
  delay(1);
}
void calculateDistante(unsigned long elapsedtime){
    fuel += (out_freq[0]/1000)*elapsedtime;
    if (fuel > 500.0){
    tank-=fuel;
    fuel=0.0;       
    EEPROM.put(20, tank); 
    }
  odometer += (elapsedtime*out_freq[1])/((float) speedSensor); //meters
  if (odometer > 500.0){
    tripA += odometer;
    totalMileage += odometer;
    odometer = 0.0;
    EEPROM.put(4, totalMileage);
    EEPROM.put(31, tripA);
  }
}

void speedManager(int currentSpeed){
    /* Emergency Stop Signal */
    unsigned long elapsedTime = millis() - last_millis;
    unsigned long deceleration = (currentSpeed - lastSpeed)/(elapsedTime*1000);
    lastSpeed = currentSpeed; 
    if (digitalRead(breakLight) == HIGH && deceleration > 28){
      pulsePinOnce(RL_HZ,500);
    }

    /* door lock */
    if (doorLockspd > 0 && !doorLocked && currentSpeed > doorLockspd){
      pulsePinOnce(RL_DL,300);
      doorLocked=true;
    }
    
  /* Speed limit */
  if (speedLimit > 0){
    if (currentSpeed > speedLimit){
        if (settings % 2 == 0) //continuo ou curto
          digitalWrite(beep,HIGH);
        else{
          if (!speedBeep){
          pulsePinOnce(beep,80);
          pulsePinOnce(beep,80);
          }
        }
        speedBeep=true;
    }
    else{
      digitalWrite(beep,LOW);
      speedBeep=false;
    }
  }
}

int alertsManager(int rpm){
  if (rpmLimit > 0){
    if (rpm > rpmLimit){
      digitalWrite(beep,HIGH);
      rpmBeep=true;
    }else{
      if (rpmBeep){
        digitalWrite(beep,LOW);
        rpmBeep=false;
      }  
    }
  }
  int sensorPressureVal = map(analogRead(A2), 204, 1024, 0, 10000);
  if (rpmAlert > 0 && rpm > rpmAlert && sensorPressureVal < minPressure){
    digitalWrite(RL_P,HIGH);
    setOutFrequency(3,2);
  }
  return sensorPressureVal;
}


/* This timer runs 3k times a second and verify if need to change state of any pulse output
 */
#ifdef is_ESP32
void IRAM_ATTR onTimer(){
 timerLoop(); 
}
#else

ISR(TIMER1_COMPA_vect) {
   timerLoop();
}
#endif

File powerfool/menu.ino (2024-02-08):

#ifndef is_ESP32
#include <avr/pgmspace.h>
#else
#define F(s) (s)
#endif
/* 
* See memutils diagram of the memory usage
*/

#ifdef is_ESP32
  void resetFunc(){}
#else
  void(* resetFunc) (void) = 0;
#endif

void printBannerMsg(const char *message){
  Serial.println(F("|****************************|"));
  Serial.print(F("|**| "));
  Serial.print(message); 
  for (int i=strlen(message)-1; i < 20; i++)
    Serial.print(" ");
  Serial.println(F("|**|"));
  Serial.println(F("|****************************|"));
  Serial.println("");
}

void Menu() {
  if (diagnostic_mode)
    return;
  printBannerMsg("Dashlane  Setup Menu");
  Serial.println(F("Select one of the following options:"));
  Serial.println(F("1 Ajustes"));
  Serial.println(F("2 Funcoes especiais"));
  Serial.println(F("3 Modo diagnostico"));
  Serial.println(F("4 Sair do menu"));
  Serial.println(F("5 Entradas e saidas"));
  if (getBit(2))
    Serial.println(F("6 Relatorio de teste"));
  Serial.println(F("7 Reset de fabrica"));
  Serial.println(F("T Modo Teste"));
  Serial.println(F("9 Reboot"));
  Serial.print(F("* Version:"));
  Serial.println(SW_VERSION,DEC);
 
    for (;;) {
        switch (Serial.read()) {
            case '1': subMenu_a(); break;
            case '2': subMenu_e(); break;
            case '3': diagnostic_mode=true; break;
            case '4': Serial.println(F("bye...")); Serial.end();
            case '5': subMenu_p(); break;
            case '7': resetFab(); break;
            case '9': 
                      resetFunc();
                      break;
            case 'T':
            case 't':
                      settingsChange(2);
                      break;
            case '6': if (getBit(2))
                        testReport();
                      break;

            default: continue;  // includes the case 'no input'
        }
      Menu();
      break;
    }
}
/* Prompt user and store a numerical parameter */
/* Params: memory position, min and max values */
void subMenu_range(unsigned char position, char min, char max){
  if (min > max){
    int temp = max;
    max=min;
    min = temp;
  }
  unsigned char value;
  EEPROM.get(position,value);
  Serial.println("");
  Serial.print(F("*** Valor em memoria: "));
  Serial.println(pinToName(value));
  Serial.println(F("+ Proximo"));
  Serial.println(F("- Anterior"));
  Serial.println(F("s Sair do menu"));
    for (;;) {
        switch (Serial.read()) {
            case '+':
              value++;
              if (value > max)
                value=min;
              Serial.print(F("*** Novo valor: "));
              Serial.println(pinToName(value));
  		        break;
            case '-':
              value--;
              if (value < min)
                value=max;
              Serial.print(F("*** Novo valor: "));
              Serial.println(pinToName(value));
              break;
            case 's': 
            case 'S': 
                Serial.println("Salvando valor...");
                Serial.println(value);
                EEPROM.put(position, (unsigned char) value);
                return;
            default: continue;  // includes the case 'no input'
        }
    }
}

/* Prompt user and store a numerical parameter */
/* Params: memory position, if is percentage, and data type */
void subMenu_num(int position, bool isPercent, varType t){
  unsigned char step;
  int value;
  EEPROM.get(position,value);
  Serial.println("");
  Serial.print(F("*** Valor em memoria: "));
  static int upperLimit, lowerLimit;
  switch(t){
      case UCHAR:
          step=1;
          upperLimit=256;
          lowerLimit=0;
          break;
      case INT:
          step=50;
          upperLimit=32718;
          lowerLimit=upperLimit*-1;
          break;
    default:
    break;
  }
  if (isPercent){
      Serial.print(memValueToCorrection(value));
      Serial.println("%");
      Serial.println(F("Valor entre -99 (%) e +400 (%), sendo 0 sem correcao"));
  } else {
      Serial.println(value);
      if (t == INT)
        Serial.println(F("Valor entre 0 e 32 mil, sendo 0 desabilitado"));
      else
        Serial.println(F("Valor entre 0 e 250, sendo 0 desabilitado"));
  }
  Serial.println(F("+ Aumentar"));
  Serial.println(F("- Diminuir"));
  Serial.println(F("a Aumentar 10x"));
  Serial.println(F("d Diminuir 10x"));
  Serial.println(F("0 deixar sem correcao"));
  Serial.println(F("s Sair do menu"));
    for (;;) {
        switch (Serial.read()) {
            case '0':
              value=0;
              numberEntry(value,position,isPercent);
              break;
            case '+':
              if (value >= upperLimit)
                value = upperLimit;
              else
          		  value+=step;
              numberEntry(value,position,isPercent);
  		        break;
            case '-':
                if (value <= lowerLimit)
                   value = lowerLimit;
                else
                  value-=step;
              	numberEntry(value,position,isPercent);
              	break;
            case 'a': 
            case 'A': 
                if (value >= upperLimit-(step*10))
                  value = upperLimit-(step*10);
                else
                  value+=(step*10);
         			numberEntry(value,position,isPercent);
         			break;
            case 'd':
            case 'D':  
                if (value <= lowerLimit+(step*10))
                  value = lowerLimit+(step*10);
                else
                  value-=(step*10);
         			numberEntry(value,position,isPercent);
         			break;
            case 's': 
            case 'S': 
                Serial.println("Salvando valor...");
                if (isPercent){
                  Serial.println(memValueToCorrection(value));
                }else{
                  Serial.println(value);
                }
                if (t == UCHAR)
                  EEPROM.put(position, (unsigned char) value);
                else
                  EEPROM.put(position, (int) value);
                return;
            default: continue;  // includes the case 'no input'
        }
    }
}

void settingsChange(unsigned char num){
  int bitv = (1 << num);
  settings ^= bitv;
  EEPROM.put(18, (int) settings);
}

int getBit(int posicao) {
  // Verifica se a posição fornecida é válida (0 a 31 para um int de 32 bits)
  if (posicao >= 0 && posicao < sizeof(int) * 8) {
    int bitv = 1 << posicao; // Cria uma máscara para isolar o bit na posição especificada
    return (settings & bitv) ? 1 : 0; // Verifica o valor do bit e retorna 1 ou 0
  } else {
    // Trate o caso de posição inválida aqui, se necessário
    return -1; // Ou outro valor de erro
  }
}
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

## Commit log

2022-07-18 Adicionando código arduino
2022-07-18 Board used in automobile
2022-07-21 correcoes de codigo
2022-08-10 Correcao de bugs e implementacao odometro
    [powerfool.ino]
2022-08-11 code refactoring e implementacao odometro trip A
2022-08-22 Update powerfool.ino
    Corrigindo arrendontamento float
    [powerfool.ino]
2022-09-02 bug fix do odometro
    [menu.ino]
2022-09-20 pressao de sensores
2022-09-26 parametrize speed sensor
2022-11-07 Bug fix and smooth output frequency
    [menu.ino, powerfool.ino]
2022-12-07 Suporte esp32
2023-01-04 new schematic
2023-02-08 correcao para mostrar temperatura
2023-03-05 Correção de bug
2024-01-18 Correcores de defeitos e melhorias
2024-02-01 Rename Dashlane case.stl to dashlane/Dashlane case.stl
    [Dashlane case.stl]
2024-02-07 melhorando leitura de sinais e refactoring de codigo
2024-02-07 melhorando saida de pwm
